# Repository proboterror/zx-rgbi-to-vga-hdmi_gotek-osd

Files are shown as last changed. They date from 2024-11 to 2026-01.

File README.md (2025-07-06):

# zx-rgbi-to-vga-hdmi

For detailed hardware and original software information, please refer to the source: [ZX_RGBI2VGA-HDMI](https://github.com/AlexEkb4ever/ZX_RGBI2VGA-HDMI/).

## Changes and New Features

### Software

- **Video Output:**
  - Added new resolutions on VGA output (800x600, 1024x768, 1280x1024).
  - Introduced scanline effect at higher resolutions.
- **Configuration via Serial Terminal:**
  - Text-based menus.
  - Frequency presets for self-synchronizing capture mode (supports ZX Spectrum 48K/128K timings).
  - Real-time settings adjustments for capture delay, image position, scanline effects, and buffering modes.
- **PIO Clock Divider Optimization:** Enhanced precision in self-synchronizing capture mode.
- **Test/Welcome Screen:** Styled like the ZX Spectrum 128K.
- **GOTEK floppy drive emulator [I2C OSD](ZX_RGBI_TO_VGA_HDMI/gotek_i2c_osd.c):** [FlashFloppy](https://github.com/keirf/flashfloppy) firmware I2C 40x4 on-screen display, VGA and HDMI output supported.
- **PS/2 Keyboard:** PS/2 - ZX Spectrum 58-key extended keyboard interface with CH446Q analog switch array in serial mode.
- **GOTEK control:** Navigate FlashFloppy menu with PS/2 keyboard.

### Hardware

- **Analog to Digital Conversion:** Converts Analog RGB to digital RGBI.
  - Based on the [RGBtoHDMI](https://github.com/hoglet67/RGBtoHDMI) project.

### Removed Features

- Z80 CLK external clock source.

# GOTEK floppy drive emulator with flashfloppy firmware I2C LCD OSD interface.

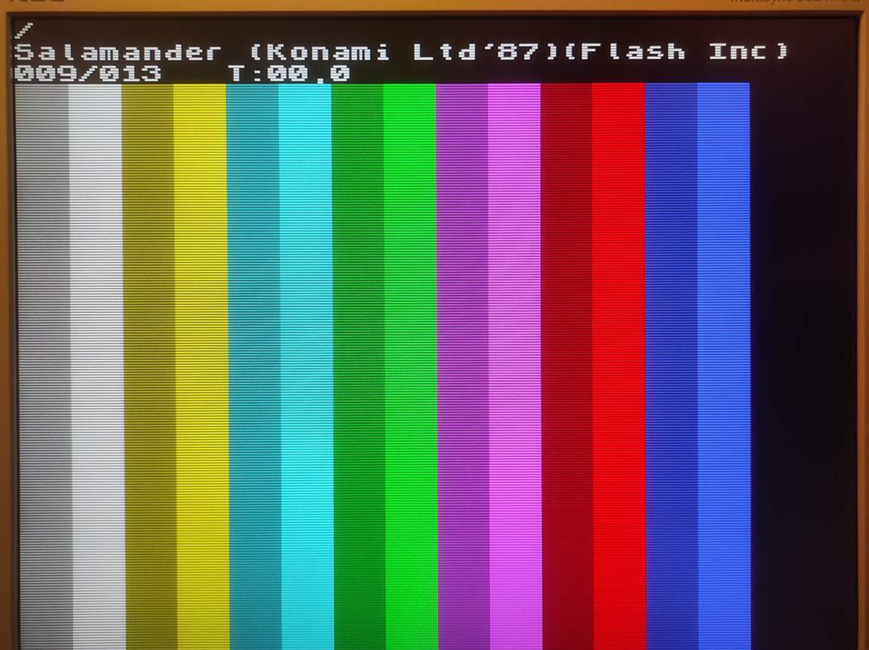
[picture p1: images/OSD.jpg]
OSD


_TL;DR: Connect GOTEK SDA and SCL pins to Pico GP16/GP17 pins (GP26/27 for RP2040-Zero). SDA and SCL lines should be pulled up to 3.3V with 4.7~10K resistors. Also support PS/2 keyboard for ZX Spectrum and OSD control._

VGA and HDMI OSD output implemented.<br>
OSD can be controlled with connected PS/2 keyboard.

Based on [flashfloppy-osd](https://github.com/keirf/flashfloppy-osd/) 1.9 by Keir Fraser<br>
Implementation: [github.com/proboterror](https://github.com/proboterror)

I2C communications to the host:
1. Emulate HD44780 LCD controller via a PCF8574 I2C backpack. Supported screen size 20x4 characters.
2. Support extended custom FF OSD protocol with bidirectional comms, up to 40x4 characters.

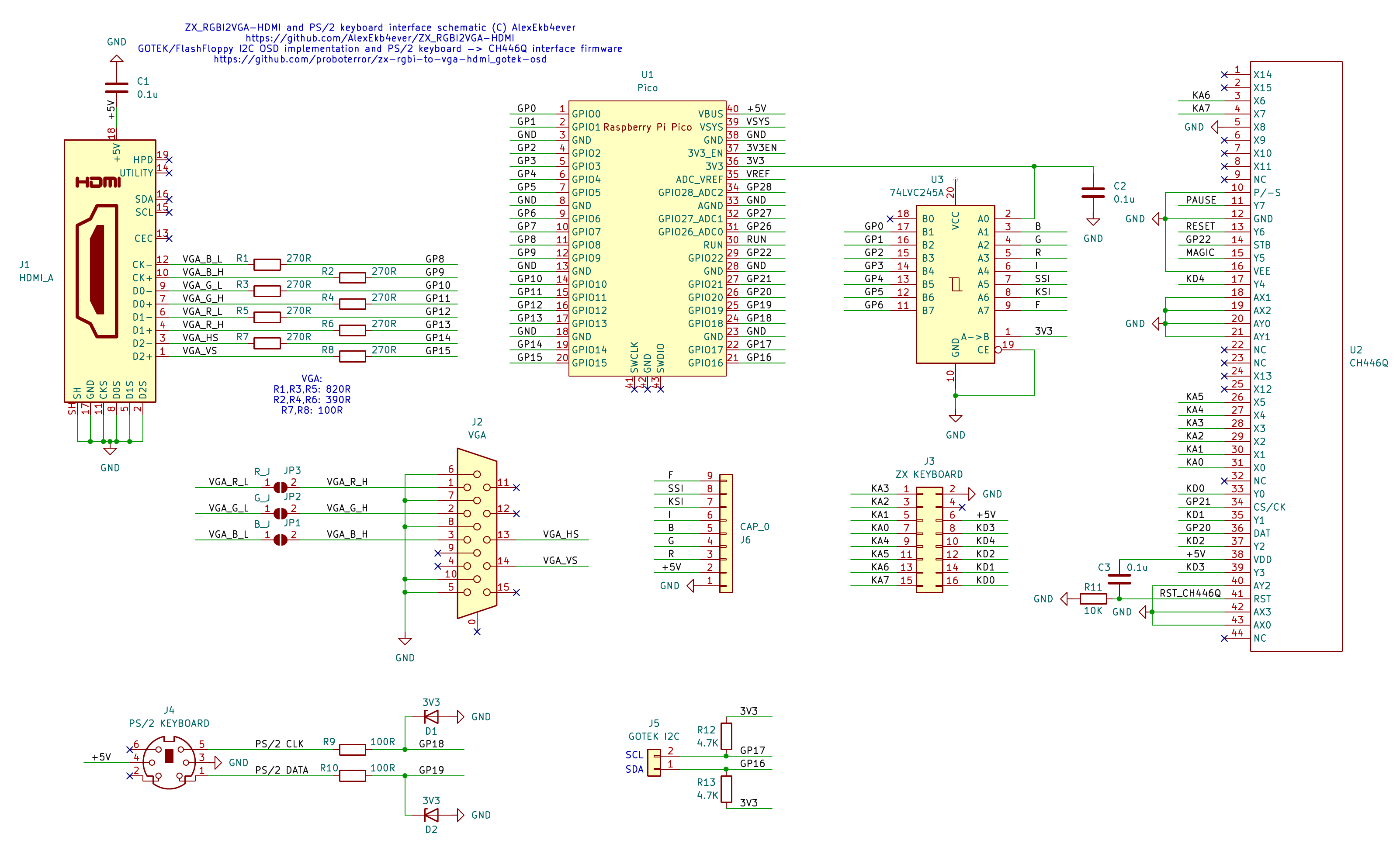
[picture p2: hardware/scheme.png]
scheme


## Compile:

Use Visual Studio Code.

Install "Arduino Community Edition" extension.<br>
Check and correct paths to rp2040 packages / Arduino CLI executable in .vscode/c_cpp_properties.json and scripts/make.ps1.

Run "Terminal/Run Task.../Build"

Do not use Arduino IDE, it uses different SDK / libraries resulting in capture sync issues.

Add
'#define WAVESHARE_RP2040_ZERO'
in g_config.h when targeting WaveShare RP2040-Zero.

## RP Pico Configuration:
- Connect host computer to Raspberry Pi Pico USB. Do not forget to disconnect +5V line from ZX.
- Use putty / minicom to connect to RP Pico COM port (9600 baud).<br>
- Press 'h' for menu help.

## GOTEK/FlashFloppy OSD wiring:
I2C OSD uses 2 wires: SDA and SCL to connect RGBI2VGA adapter and GOTEK. Connect GOTEK SDA and SCL pins to Pico GP16/GP17 pins. SDA and SCL lines should be pulled up to VCC(3.3V) with 4.7~10K resistors on GOTEK or RGBI2VGA side.

OSD also can be used with any device supporting LCD PCF8574 16x2/20x4 protocol.

WaveShare RP2040-Zero board supported with keyboard interface disabled (GP26/GP27 for SDA/SCL).

## GOTEK/FlashFloppy configuration:
GOTEK configuration:<br>
[flashfloppy/wiki/Hardware-Mods#lcd-display](https://github.com/keirf/flashfloppy/wiki/Hardware-Mods#lcd-display)<br>
[flashfloppy/wiki/FF.CFG-Configuration-File](https://github.com/keirf/flashfloppy/wiki/FF.CFG-Configuration-File)

FF.CFG:<br>
for FF OSD protocol with dual OLED/LCD support:<br>
set:
`display-type=auto`
or
`display-type = oled-128x64`
with
`osd-display-order = 3,0`
`osd-columns = 40`
and
`display-off-secs = 0-255 (60 by default)`

display-order and osd-display-order can be set independently.

for single PCF8574 20x4 LCD display protocol:<br>
set:
`display-type=lcd-20x04`
with
`display-order=3,0,2,1`
and
`display-off-secs = 0-255 (60 by default)`

Russian filenames are supported, requires [flashfloppy-russian](https://github.com/proboterror/flashfloppy-russian) patched flashfloppy GOTEK firmware.

## PS/2 Keyboard support:
- Selected USB keyboards can be used with passive USB->PS/2 adapter: requires explicit support in keyboard's internal controller. Not tested.

## GOTEK/FlashFloppy OSD hotkeys:
- CTRL+RIGHT - right
- CTRL+LEFT - left
- CTRL+UP - directory up
- CTRL+DOWN - select item

## Special keys:
- F10 - PAUSE (Z80 BUSRQ/) (trigger)
- F11 - MAGIC (Z80 NMI/)
- F12 - RESET (Z80 RST/)

## Special keys wiring:
- Input: CH446Q pin 5: common/GND
- Output: CH446Q pin 15: MAGIC, pin 13: RESET, pin 11: PAUSE.

## Test features:
Ветка с реализацией поддержки [SetupGUI](https://github.com/proboterror/zx-rgbi-to-vga-hdmi_gotek-osd/tree/SetupGUI) и доработками от Дмитрий Стародубцев (@cinsler78).

Selectable runtime HDMI palettes in [separate branch](https://github.com/proboterror/zx-rgbi-to-vga-hdmi_gotek-osd/tree/hdmi_rgb-palette) (setting save not implemented).

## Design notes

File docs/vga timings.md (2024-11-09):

# VGA timings

The table contains the timing parameters for all VGA modes supported in this project.

| Mode | 640 x 480 | | 800 x 600 | | 1024 x 768 | | 1280 x 1024 | |
|---|---:|---:|---:|---:|---:|---:|---:|---:|
| **Screen refresh rate** | 60 Hz | | 60 Hz | | 60 Hz | | 60 Hz | |
| **Vertical refresh** | 31.46875 kHz | | 37.878787878788 kHz | | 48.363095238095 kHz | | 63.981042654028 kHz | |
| **Pixel frequency** | 25.175 MHz | | 40.0 MHz | | 65.0 MHz | | 108.0 MHz | |
| | | | | | | | | |
| **Horizontal timing (line)** | | | | | | | | |
| **Polarity of horizontal sync pulse** | negative | | positive | | negative | | positive | |
| **Scanline part** | **Pixels** | **Time [µs]** | **Pixels** | **Time [µs]** | **Pixels** | **Time [µs]** | **Pixels** | **Time [µs]** |
| **Visible area** | 640 | 25.422045680238 | 800 | 20 | 1024 | 15.753846153846 | 1280 | 11.851851851852 |
| **Front porch** | 16 | 0.63555114200596  | 40 | 1 | 24 | 0.36923076923077  | 48 | 0.44444444444444  |
| **Sync pulse** | 96 | 3.8133068520357 | 128 | 3.2 | 136 | 2.0923076923077 | 112 | 1.037037037037 |
| **Back porch** | 48 | 1.9066534260179 | 88 | 2.2 | 160 | 2.4615384615385 | 248 | 2.2962962962963 |
| **Whole line** | 800 | 31.777557100298 | 1056 | 26.4 | 1344 | 20.676923076923 | 1688 | 15.62962962963 |
| | | | | | | | | |
| **Vertical timing (frame)** | | | | | | | | |
| **Polarity of vertical sync pulse** | negative | | positive | | negative | | positive | |
| **Frame part** | **Lines** | **Time [µs]** | **Lines** | **Time [µs]** | **Lines** | **Time [µs]** | **Lines** | **Time [µs]** |
| **Visible area** | 480 | 15.253227408143 | 600 | 15.84 | 768 | 15.879876923077 | 1024 | 16.004740740741 |
| **Front porch** | 10 | 0.31777557100298  | 1 | 0.0264 | 3 | 0.062030769230769 | 1 | 0.01562962962963  |
| **Sync pulse** | 2 | 0.063555114200596 | 4 | 0.1056 | 6 | 0.12406153846154  | 3 | 0.046888888888889 |
| **Back porch** | 33 | 1.0486593843098 | 23 | 0.6072 | 29 | 0.59963076923077  | 38 | 0.59392592592593  |
| **Whole frame** | 525 | 16.683217477656 | 628 | 16.5792 | 806 | 16.6656 | 1066 | 16.661185185185 |

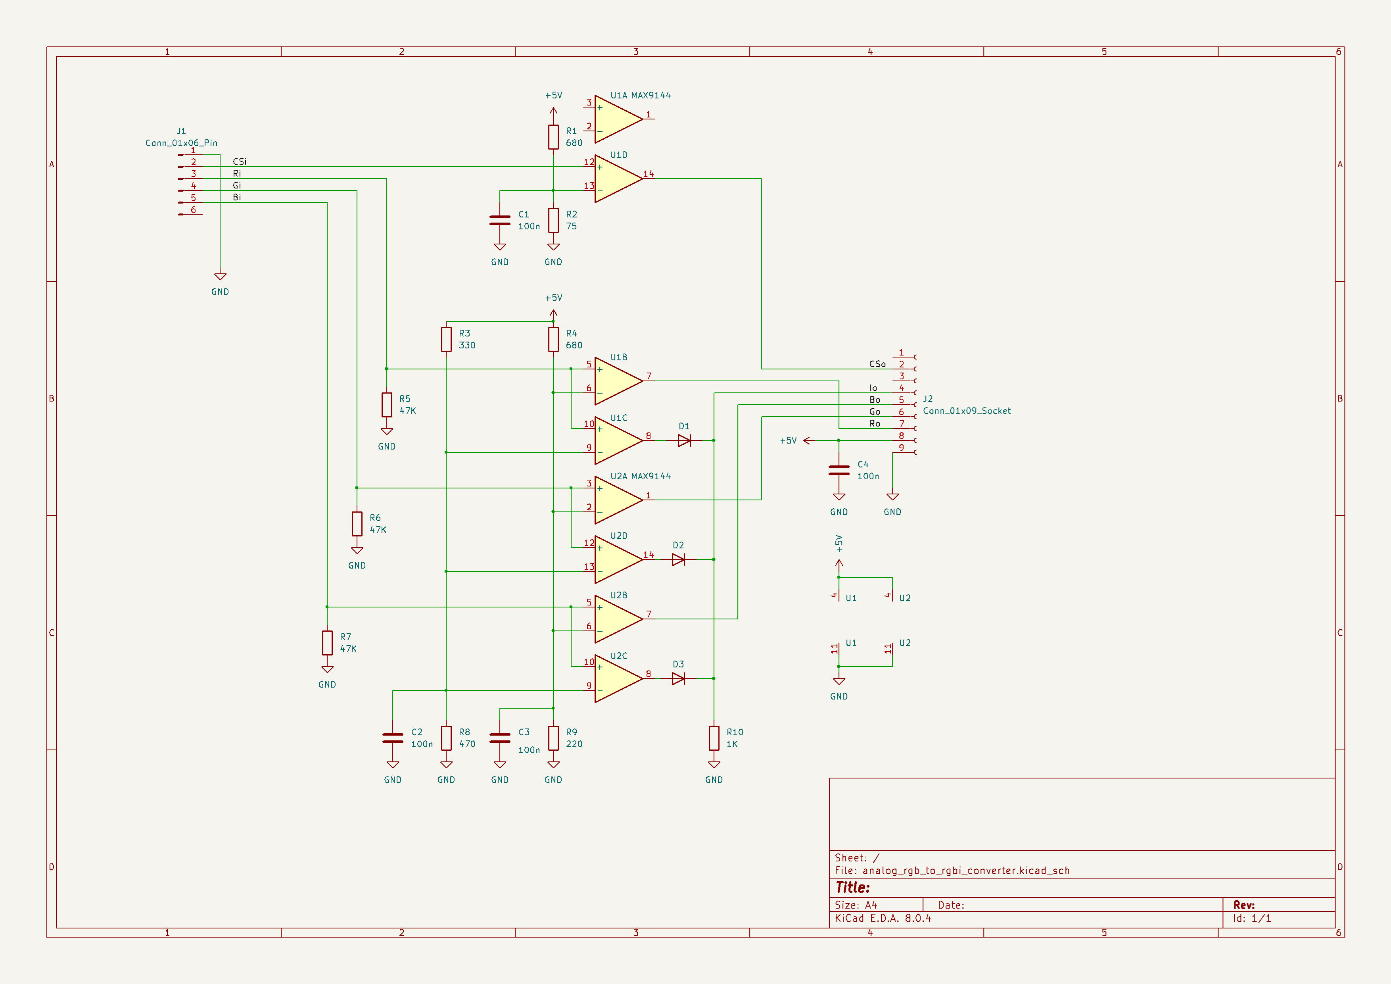
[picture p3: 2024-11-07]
hardware/analog_rgb_to_rgbi_converter.png

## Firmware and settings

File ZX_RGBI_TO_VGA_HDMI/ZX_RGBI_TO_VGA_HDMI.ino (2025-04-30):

#include <Arduino.h>
#include <typeinfo>

extern "C"
{
#include "g_config.h"
#include "dvi.h"
#include "rgb_capture.h"
#include "v_buf.h"
#include "vga.h"
#include "gotek_i2c_osd.h"
#include "ps2_keyboard.h"
#include "zx_keyboard.h"

#include "hardware/flash.h"
}

// Default settings values for Deltagon 1.6+
settings_t settings = {
  .video_out_mode = DVI,
  .scanlines_mode = false,
  .x3_buffering_mode = false,
  .video_sync_mode = true,
  .cap_sync_mode = EXT,
  .frequency = 7000000,
  .ext_clk_divider = 1,
  .delay = 20,
  .shX = 137,
  .shY = 40,
  .pin_inversion_mask = 0b01011111,
};

video_mode_t video_mode;

const int *saved_settings = (const int *)(XIP_BASE + (PICO_FLASH_SIZE_BYTES - FLASH_SECTOR_SIZE));
bool start_core0 = false;

// https://en.wikipedia.org/wiki/Fletcher's_checksum
uint16_t Fletcher16(uint8_t *data, int count)
{
  uint16_t sum1 = 0;
  uint16_t sum2 = 0;
  int index;

  for (index = 0; index < count; ++index)
  {
    sum1 = (sum1 + data[index]) % 255;
    sum2 = (sum2 + sum1) % 255;
  }

  return (sum2 << 8) | sum1;
}

struct flash_settings_t
{
  settings_t settings;
  uint16_t checksum;
};

void save_settings(settings_t *settings)
{
  Serial.println("  Saving settings...");

  check_settings(settings);

  flash_settings_t* flash_settings = (flash_settings_t*)malloc(FLASH_PAGE_SIZE);

  *flash_settings = {
    *settings,
    Fletcher16((uint8_t*)settings, sizeof(settings_t))
  };

  rp2040.idleOtherCore();
  uint32_t ints = save_and_disable_interrupts();

  flash_range_erase((PICO_FLASH_SIZE_BYTES - FLASH_SECTOR_SIZE), FLASH_SECTOR_SIZE);
  flash_range_program((PICO_FLASH_SIZE_BYTES - FLASH_SECTOR_SIZE), (uint8_t *)flash_settings, FLASH_PAGE_SIZE);

  // restore_interrupts(ints);
  // rp2040.resumeOtherCore();
}

void print_byte_hex(uint8_t byte)
{
  if (byte < 16)
    Serial.print("0");

  Serial.print(byte, HEX);
}

String binary_to_string(uint8_t value, bool mask_1)
{
  uint8_t binary = value;
  String str = "";

  for (int i = 0; i < 8; i++)
  {
    str += binary & 0b10000000 ? (mask_1 ? "X" : "1") : "0";
    binary <<= 1;
  }

  return str;
}

void print_main_menu()
{
  Serial.println("");
  Serial.print("      * ZX RGB(I) to VGA/HDMI ");
  Serial.print(FW_VERSION);
  Serial.println(" *");
  Serial.println("");
  Serial.println("  v   set video output mode");
  Serial.println("  s   set scanlines mode");
  Serial.println("  b   set buffering mode");
  Serial.println("  c   set capture synchronization source");
  Serial.println("  f   set capture frequency");
  Serial.println("  d   set external clock divider");
  Serial.println("  y   set video sync mode");
  Serial.println("  t   set capture delay and image position");
  Serial.println("  m   set pin inversion mask");
  Serial.println("");
  Serial.println("  p   show configuration");
  Serial.println("  h   show help (this menu)");
  Serial.println("  q   exit configuration mode");
  Serial.println("  w   save configuration and restart");
  Serial.println("");
}

void print_video_out_menu()
{
  Serial.println("");
  Serial.println("      * Video output mode *");
  Serial.println("");
  Serial.println("  1   HDMI   640x480 (div 2)");
  Serial.println("  2   VGA    640x480 (div 2)");
  Serial.println("  3   VGA    800x600 (div 2)");
  Serial.println("  4   VGA   1024x768 (div 3)");
  Serial.println("  5   VGA  1280x1024 (div 3)");
  Serial.println("  6   VGA  1280x1024 (div 4)");
  Serial.println("");
  Serial.println("  p   show configuration");
  Serial.println("  h   show help (this menu)");
  Serial.println("  q   exit to main menu");
  Serial.println("");
}

void print_scanlines_mode_menu()
{
  Serial.println("");
  Serial.println("      * Scanlines mode *");
  Serial.println("");
  Serial.println("  s   change scanlines mode");
  Serial.println("");
  Serial.println("  p   show configuration");
  Serial.println("  h   show help (this menu)");
  Serial.println("  q   exit to main menu");
  Serial.println("");
}

void print_buffering_mode_menu()
{
  Serial.println("");
  Serial.println("      * Buffering mode *");
  Serial.println("");
  Serial.println("  b   change buffering mode");
  Serial.println("");
  Serial.println("  p   show configuration");
  Serial.println("  h   show help (this menu)");
  Serial.println("  q   exit to main menu");
  Serial.println("");
}

void print_cap_sync_mode_menu()
{
  Serial.println("");
  Serial.println("      * Capture synchronization source *");
  Serial.println("");
  Serial.println("  1   self-synchronizing");
  Serial.println("  2   external clock");
  Serial.println("");
  Serial.println("  p   show configuration");
  Serial.println("  h   show help (this menu)");
  Serial.println("  q   exit to main menu");
  Serial.println("");
}

void print_capture_frequency_menu()
{
  Serial.println("");
  Serial.println("      * Capture frequency *");
  Serial.println("");
  Serial.println("  1   7000000 Hz (ZX Spectrum  48K)");
  Serial.println("  2   7093790 Hz (ZX Spectrum 128K)");
  Serial.println("  3   custom");
  Serial.println("");
  Serial.println("  p   show configuration");
  Serial.println("  h   show help (this menu)");
  Serial.println("  q   exit to main menu");
  Serial.println("");
}

void print_ext_clk_divider_menu()
{
  Serial.println("");
  Serial.println("      * External clock divider *");
  Serial.println("");
  Serial.println("  a   increment divider (+1)");
  Serial.println("  z   decrement divider (-1)");
  Serial.println("");
  Serial.println("  p   show configuration");
  Serial.println("  h   show help (this menu)");
  Serial.println("  q   exit to main menu");
  Serial.println("");
}

void print_video_sync_mode_menu()
{
  Serial.println("");
  Serial.println("      * Video synchronization mode *");
  Serial.println("");
  Serial.println("  y   change synchronization mode");
  Serial.println("");
  Serial.println("  p   show configuration");
  Serial.println("  h   show help (this menu)");
  Serial.println("  q   exit to main menu");
  Serial.println("");
}

void print_image_tuning_menu()
{
  Serial.println("");
  Serial.println("      * Capture delay and image position *");
  Serial.println("");
  Serial.println("  a   increment delay (+1)");
  Serial.println("  z   decrement delay (-1)");
  Serial.println("");
  Serial.println("  i   shift image UP");
  Serial.println("  k   shift image DOWN");
  Serial.println("  j   shift image LEFT");
  Serial.println("  l   shift image RIGHT");
  Serial.println("");
  Serial.println("  p   show configuration");
  Serial.println("  h   show help (this menu)");
  Serial.println("  q   exit to main menu");
  Serial.println("");
}

void print_pin_inversion_mask_menu()
{
  Serial.println("");
  Serial.println("      * Pin inversion mask *");
  Serial.println("");
  Serial.println("  m   set pin inversion mask");
  Serial.println("");
  Serial.println("  p   show configuration");
  Serial.println("  h   show help (this menu)");
  Serial.println("  q   exit to main menu");
  Serial.println("");
}

void print_test_menu()
{
  Serial.println("");
  Serial.println("      * Test *");
  Serial.println("");
  Serial.println("  1   draw welcome image (vertical stripes)");
  Serial.println("  2   draw welcome image (horizontal stripes)");
  Serial.println("  i   show captured frame count");
  Serial.println("");
  Serial.println("  p   show configuration");
  Serial.println("  h   show help (this menu)");
  Serial.println("  q   exit to main menu");
  Serial.println("");
}

void print_video_out_mode()
{
  Serial.print("  Video output mode ........... ");
  switch (settings.video_out_mode)
  {
  case DVI:
    Serial.println("HDMI 640x480");
    break;

  case VGA640x480:
    Serial.println("VGA 640x480");
    break;

  case VGA800x600:
    Serial.println("VGA 800x600");
    break;

  case VGA1024x768:
    Serial.println("VGA 1024x768");
    break;

  case VGA1280x1024_d3:
    Serial.println("VGA 1280x1024 (div 3)");
    break;

  case VGA1280x1024_d4:
    Serial.println("VGA 1280x1024 (div 4)");
    break;

  default:
    break;
  }
}

void print_scanlines_mode()
{
  Serial.print("  Scanlines ................... ");

  if (settings.scanlines_mode)
    Serial.println("enabled");
  else
    Serial.println("disabled");
}

void print_buffering_mode()
{
  Serial.print("  Buffering mode .............. ");

  if (settings.x3_buffering_mode)
    Serial.println("x3");
  else
    Serial.println("x1");
}

void print_cap_sync_mode()
{
  Serial.print("  Capture sync source ......... ");
  switch (settings.cap_sync_mode)
  {
  case SELF:
    Serial.println("self-synchronizing");
    break;

  case EXT:
    Serial.println("external clock");
    break;

  default:
    break;
  }
}

void print_capture_frequency()
{
  Serial.print("  Capture frequency ........... ");
  Serial.print(settings.frequency, DEC);
  Serial.println(" Hz");
}

void print_ext_clk_divider()
{
  Serial.print("  External clock divider ...... ");
  Serial.println(settings.ext_clk_divider, DEC);
}

void print_capture_delay()
{
  Serial.print("  Capture delay ............... ");
  Serial.println(settings.delay, DEC);
}

void print_x_offset()
{
  Serial.print("  X offset .................... ");
  Serial.println(settings.shX, DEC);
}

void print_y_offset()
{
  Serial.print("  Y offset .................... ");
  Serial.println(settings.shY, DEC);
}

void print_dividers()
{
  uint16_t div_int;
  uint8_t div_frac;

  video_mode_t video_mode = *(vga_modes[settings.video_out_mode]);

  Serial.println("");

  Serial.print("  System clock frequency ...... ");
  Serial.print(clock_get_hz(clk_sys), 1);
  Serial.println(" Hz");

  Serial.println("  Capture divider");

  Serial.print("    calculated (SDK) .......... ");

  pio_calculate_clkdiv_from_float((float)clock_get_hz(clk_sys) / (settings.frequency * 12.0), &div_int, &div_frac);

  Serial.print((div_int + (float)div_frac / 256), 8);

  Serial.print(" ( ");
  Serial.print("0x");
  print_byte_hex((uint8_t)(div_int >> 8));
  print_byte_hex((uint8_t)(div_int & 0xff));
  print_byte_hex(div_frac);
  Serial.println(" )");

  Serial.print("    optimized ................. ");

  calculate_clkdiv(settings.frequency, &div_int, &div_frac);

  Serial.print((div_int + (float)div_frac / 256), 8);

  Serial.print(" ( ");
  Serial.print("0x");
  print_byte_hex((uint8_t)(div_int >> 8));
  print_byte_hex((uint8_t)(div_int & 0xff));
  print_byte_hex(div_frac);
  Serial.println(" )");

  Serial.print("  Video output clock divider .. ");

  pio_calculate_clkdiv_from_float(((float)clock_get_hz(clk_sys) * video_mode.div) / video_mode.pixel_freq, &div_int, &div_frac);

  Serial.print((div_int + (float)div_frac / 256), 8);

  Serial.print(" ( ");
  Serial.print("0x");
  print_byte_hex((uint8_t)(div_int >> 8));
  print_byte_hex((uint8_t)(div_int & 0xff));
  print_byte_hex(div_frac);
  Serial.println(" )");

  Serial.println("");
}

void print_video_sync_mode()
{
  Serial.print("  Video synchronization mode .. ");
  if (settings.video_sync_mode)
    Serial.println("separate");
  else
    Serial.println("composite");
}

void print_pin_inversion_mask()
{
  Serial.print("  Pin inversion mask .......... ");
  Serial.println(binary_to_string(settings.pin_inversion_mask, false));
}

void print_settings()
{
  Serial.println("");
  print_video_out_mode();
  print_scanlines_mode();
  print_buffering_mode();
  print_cap_sync_mode();
  print_capture_frequency();
  print_ext_clk_divider();
  print_video_sync_mode();
  print_capture_delay();
  print_x_offset();
  print_y_offset();
  print_pin_inversion_mask();
  print_dividers();
  Serial.println("");
}

void set_scanlines_mode()
{
  if (settings.video_out_mode != DVI)
    set_vga_scanlines_mode(settings.scanlines_mode);
}

void setup()
{
  setup_i2c_slave();
#ifndef WAVESHARE_RP2040_ZERO
  zx_keyboard_init();
  ps2_keyboard_init();
#endif
  Serial.begin(9600);

  // loading saved settings
  const flash_settings_t *flash_settings = (flash_settings_t*)saved_settings;
  const uint16_t checksum = Fletcher16((uint8_t*)saved_settings, sizeof(settings_t));

  if(checksum == flash_settings->checksum)
    memcpy(&settings, saved_settings, sizeof(settings_t));

  // correct if there is garbage in the cells
  check_settings(&settings);

  set_v_buf_buffering_mode(settings.x3_buffering_mode);

  draw_welcome_screen(*(vga_modes[settings.video_out_mode]));

  set_scanlines_mode();

  if (settings.video_out_mode == DVI)
  {
    start_dvi(*(vga_modes[settings.video_out_mode]));
  }
  else
  {
    start_vga(*(vga_modes[settings.video_out_mode]));
  }

  start_core0 = true;

  Serial.println("  Starting...");
  Serial.println("");
}

void loop()
{
  char inbyte = 0;

  while (1)
  {
    sleep_ms(500);

    if (Serial.available())
    {
      inbyte = 'h';
      break;
    }
  }

  Serial.println(" Entering the configuration mode");
  Serial.println("");

  while (1)
  {
    sleep_ms(10);

    if (inbyte != 'h' && Serial.available())
      inbyte = Serial.read();

    switch (inbyte)
    {
    case 'p':
      print_settings();
      inbyte = 0;
      break;

    case 'v':
    {
      inbyte = 'h';

      while (1)
      {
        sleep_ms(10);

        if (inbyte != 'h' && Serial.available())
          inbyte = Serial.read();

        switch (inbyte)
        {
        case 'p':
          print_video_out_mode();
          break;

        case 'h':
          print_video_out_menu();
          break;

        case '1':
          settings.video_out_mode = DVI;
          print_video_out_mode();
          break;

        case '2':
          settings.video_out_mode = VGA640x480;
          print_video_out_mode();
          break;

        case '3':
          settings.video_out_mode = VGA800x600;
          print_video_out_mode();
          break;

        case '4':
          settings.video_out_mode = VGA1024x768;
          print_video_out_mode();
          break;

        case '5':
          settings.video_out_mode = VGA1280x1024_d3;
          print_video_out_mode();
          break;
        case '6':
          settings.video_out_mode = VGA1280x1024_d4;
          print_video_out_mode();
          break;

        default:
          break;
        }

        if (inbyte == 'q')
        {
          inbyte = 'h';
          break;
        }

        inbyte = 0;
      }

      break;
    }

    case 's':
    {
      inbyte = 'h';

      while (1)
      {
        sleep_ms(10);

        if (inbyte != 'h' && Serial.available())
          inbyte = Serial.read();

        switch (inbyte)
        {
        case 'p':
          print_scanlines_mode();
          break;

        case 'h':
          print_scanlines_mode_menu();
          break;

        case 's':
          settings.scanlines_mode = !settings.scanlines_mode;
          print_scanlines_mode();
          set_scanlines_mode();
          break;

        default:
          break;
        }

        if (inbyte == 'q')
        {
          inbyte = 'h';
          break;
        }

        inbyte = 0;
      }

      break;
    }

    case 'b':
    {
      inbyte = 'h';

      while (1)
      {
        sleep_ms(10);

        if (inbyte != 'h' && Serial.available())
          inbyte = Serial.read();

        switch (inbyte)
        {
        case 'p':
          print_buffering_mode();
          break;

        case 'h':
          print_buffering_mode_menu();
          break;

        case 'b':
          settings.x3_buffering_mode = !settings.x3_buffering_mode;
          print_buffering_mode();
          set_v_buf_buffering_mode(settings.x3_buffering_mode);
          break;

        default:
          break;
        }

        if (inbyte == 'q')
        {
          inbyte = 'h';
          break;
        }

        inbyte = 0;
      }

      break;
    }

    case 'c':
    {
      inbyte = 'h';

      while (1)
      {
        sleep_ms(10);

        if (inbyte != 'h' && Serial.available())
          inbyte = Serial.read();

        switch (inbyte)
        {
        case 'p':
          print_cap_sync_mode();
          break;

        case 'h':
          print_cap_sync_mode_menu();
          break;

        case '1':
          settings.cap_sync_mode = SELF;
          print_cap_sync_mode();
          break;

        case '2':
          settings.cap_sync_mode = EXT;
          print_cap_sync_mode();
          break;

        default:
          break;
        }

        if (inbyte == 'q')
        {
          inbyte = 'h';
          break;
        }

        inbyte = 0;
      }

      break;
    }

    case 'f':
    {
      inbyte = 'h';

      while (1)
      {
        sleep_ms(10);

        if (inbyte != 'h' && Serial.available())
          inbyte = Serial.read();

        switch (inbyte)
        {
        case 'p':
          print_capture_frequency();
          break;

        case 'h':
          print_capture_frequency_menu();
          break;

        case '1':
          settings.frequency = 7000000;
          print_capture_frequency();
          break;

        case '2':
          settings.frequency = 7093790;
          print_capture_frequency();
          break;

        case '3':
        {
          String str_frequency = "";
          uint32_t frequency = 0;

          Serial.print("  Enter frequency: ");

          while (1)
          {
            sleep_ms(10);
            inbyte = 0;

            if (Serial.available())
              inbyte = Serial.read();

            if (inbyte >= '0' && inbyte <= '9')
            {
              Serial.print(inbyte);
              str_frequency += inbyte;
            }

            if (inbyte == '\r')
            {
              Serial.println("");
              frequency = str_frequency.toInt();

              if (frequency >= FREQUENCY_MIN && frequency <= FREQUENCY_MAX)
              {
                settings.frequency = frequency;
                print_capture_frequency();
                break;
              }
              else
              {
                str_frequency = "";
                Serial.print("  Allowed frequency range ..... ");
                Serial.print(FREQUENCY_MIN, DEC);
                Serial.print(" - ");
                Serial.print(FREQUENCY_MAX, DEC);
                Serial.println(" Hz");
                Serial.print("  Enter frequency: ");
              }
            }
          }

          break;
        }

        default:
          break;
        }

        if (inbyte == 'q')
        {
          inbyte = 'h';
          break;
        }

        inbyte = 0;
      }

      break;
    }

    case 'd':
    {
      inbyte = 'h';

      while (1)
      {
        sleep_ms(10);

        if (inbyte != 'h' && Serial.available())
          inbyte = Serial.read();

        switch (inbyte)
        {

        case 'p':
          print_ext_clk_divider();
          break;

        case 'h':
          print_ext_clk_divider_menu();
          break;

        case 'a':
          settings.ext_clk_divider = settings.ext_clk_divider < EXT_CLK_DIVIDER_MAX ? (settings.ext_clk_divider + 1) : EXT_CLK_DIVIDER_MAX;
          print_ext_clk_divider();
          break;

        case 'z':
          settings.ext_clk_divider = settings.ext_clk_divider > EXT_CLK_DIVIDER_MIN ? (settings.ext_clk_divider - 1) : EXT_CLK_DIVIDER_MIN;
          print_ext_clk_divider();
          break;

        default:
          break;
        }

        if (inbyte == 'q')
        {
          inbyte = 'h';
          break;
        }

        inbyte = 0;
      }

      break;
    }

    case 'y':
    {
      inbyte = 'h';

      while (1)
      {
        sleep_ms(10);

        if (inbyte != 'h' && Serial.available())
          inbyte = Serial.read();

        switch (inbyte)
        {
        case 'p':
          print_video_sync_mode();
          break;

        case 'h':
          print_video_sync_mode_menu();
          break;

        case 'y':
          settings.video_sync_mode = !settings.video_sync_mode;
          print_video_sync_mode();
          set_video_sync_mode(settings.video_sync_mode);
          break;

        default:
          break;
        }

        if (inbyte == 'q')
        {
          inbyte = 'h';
          break;
        }

        inbyte = 0;
      }

      break;
    }

    case 't':
    {
      inbyte = 'h';

      while (1)
      {
        sleep_ms(10);

        if (inbyte != 'h' && Serial.available())
          inbyte = Serial.read();

        switch (inbyte)
        {

        case 'p':
          print_capture_delay();
          print_x_offset();
          print_y_offset();
          break;

        case 'h':
          print_image_tuning_menu();
          break;

        case 'a':
          settings.delay = set_capture_delay(settings.delay + 1);
          print_capture_delay();
          break;

        case 'z':
          settings.delay = set_capture_delay(settings.delay - 1);
          print_capture_delay();
          break;

        case 'i':
          settings.shY = set_capture_shY(settings.shY + 1);
          print_y_offset();
          break;

        case 'k':
          settings.shY = set_capture_shY(settings.shY - 1);
          print_y_offset();
          break;

        case 'j':
          settings.shX = set_capture_shX(settings.shX - 1);
          print_x_offset();
          break;

        case 'l':
          settings.shX = set_capture_shX(settings.shX + 1);
          print_x_offset();
          break;

        default:
          break;
        }

        if (inbyte == 'q')
        {
          inbyte = 'h';
          break;
        }

        inbyte = 0;
      }

      break;
    }

    case 'm':
    {
      inbyte = 'h';

      while (1)
      {
        sleep_ms(10);

        if (inbyte != 'h' && Serial.available())
          inbyte = Serial.read();

        switch (inbyte)
        {
        case 'p':
          print_pin_inversion_mask();
          break;

        case 'h':
          print_pin_inversion_mask_menu();
          break;

        case 'm':
        {
          String str_pin_inversion_mask = "";
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

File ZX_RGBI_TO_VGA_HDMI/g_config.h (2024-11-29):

#ifndef G_CONFIG_H
#define G_CONFIG_H

#include <Arduino.h>

#include "pico/platform.h"
#include "pico/stdlib.h"

#include "stdio.h"
#include "inttypes.h"
#include "stdbool.h"

#define FW_VERSION "v1.2.1"

enum cap_sync_mode_t
{
  SYNC_MODE_MIN,
  SELF = SYNC_MODE_MIN,
  EXT,
  SYNC_MODE_MAX = EXT,
};

enum video_out_mode_t
{
  VIDEO_MODE_MIN,
  DVI = VIDEO_MODE_MIN,
  VGA640x480,
  VGA800x600,
  VGA1024x768,
  VGA1280x1024_d3,
  VGA1280x1024_d4,
  VIDEO_MODE_MAX = VGA1280x1024_d4,
};

typedef struct settings_t
{
  enum video_out_mode_t video_out_mode;
  bool scanlines_mode : 1;
  bool x3_buffering_mode : 1;
  bool video_sync_mode : 1;
  enum cap_sync_mode_t cap_sync_mode;
  uint32_t frequency;
  uint8_t ext_clk_divider;
  int8_t delay;
  int16_t shX;
  int16_t shY;
  uint8_t pin_inversion_mask;
} settings_t;

typedef struct video_mode_t
{
  uint32_t sys_freq;
  float pixel_freq;
  uint16_t h_visible_area;
  uint16_t v_visible_area;
  uint16_t whole_line;
  uint16_t whole_frame;
  uint8_t h_front_porch;
  uint8_t h_sync_pulse;
  uint8_t h_back_porch;
  uint8_t v_front_porch;
  uint8_t v_sync_pulse;
  uint8_t v_back_porch;
  uint8_t sync_polarity;
  uint8_t div;
} video_mode_t;

extern video_mode_t vga_640x480;
extern video_mode_t vga_800x600;
extern video_mode_t vga_1024x768;
extern video_mode_t vga_1280x1024_d3;
extern video_mode_t vga_1280x1024_d4;

extern video_mode_t *vga_modes[];

extern uint8_t g_v_buf[];
extern uint32_t frame_count;

#define BOARD_CODE_36LJU22
// #define BOARD_CODE_09LJV23

// board pin configurations
#ifdef BOARD_CODE_36LJU22
// 36LJU22
// first VGA pin
#define VGA_PIN_D0 8
// DVI pins and settings
#define DVI_PIN_D0 VGA_PIN_D0
#define DVI_PIN_CLK0 (DVI_PIN_D0 + 6)

#elif defined(BOARD_CODE_09LJV23)
// 09LJV23
// first VGA pin
#define VGA_PIN_D0 7
// DVI pins and settings
#define DVI_PIN_D0 VGA_PIN_D0
#define DVI_PIN_CLK0 (DVI_PIN_D0 + 6)

#else
// defaults
// first VGA pin
#define VGA_PIN_D0 7
// DVI pins and settings
#define DVI_PIN_D0 VGA_PIN_D0
#define DVI_PIN_CLK0 (DVI_PIN_D0 + 6)

#endif

// capture pins
#ifndef CAP_PIN_D0
#define CAP_PIN_D0 0
#endif

#ifndef HS_PIN
#define HS_PIN (CAP_PIN_D0 + 4)
#endif

#ifndef VS_PIN
#define VS_PIN (CAP_PIN_D0 + 5)
#endif

#ifndef F_PIN
#define F_PIN (CAP_PIN_D0 + 6)
#endif

// DVI pins and settings
#ifndef DVI_PIN_invert_diffpairs
#define DVI_PIN_invert_diffpairs 0
#endif

#ifndef DVI_PIN_RGB_notBGR
#define DVI_PIN_RGB_notBGR 0
#endif

// PIO and SM for VGA
#define PIO_VGA_NUM 0
#if PIO_VGA_NUM == 0
#define PIO_VGA pio0
#define DREQ_PIO_VGA DREQ_PIO0_TX0
#else
#define PIO_VGA pio1
#define DREQ_PIO_VGA DREQ_PIO1_TX0
#endif

#define SM_VGA 0

// PIO and SM for DVI
#define PIO_DVI_NUM 0
#if PIO_DVI_NUM == 0
#define PIO_DVI pio0
#define DREQ_PIO_DVI DREQ_PIO0_TX0
#else
#define PIO_DVI pio1
#define DREQ_PIO_DVI DREQ_PIO0_TX0
#endif

#define SM_DVI 0

// capture PIO and SM
#define PIO_CAP_NUM 1
#if PIO_CAP_NUM == 0
#define PIO_CAP pio0
#define DREQ_PIO_CAP DREQ_PIO0_RX0
#else
#define PIO_CAP pio1
#define DREQ_PIO_CAP DREQ_PIO1_RX0
#endif

#define SM_CAP 0

// video buffer
#define V_BUF_W 448
#define V_BUF_H 306
#define V_BUF_SZ (V_BUF_H * V_BUF_W / 2)

// settings MIN values
#define VIDEO_OUT_MODE_MIN VIDEO_MODE_MIN
#define CAP_SYNC_MODE_MIN SYNC_MODE_MIN
#define FREQUENCY_MIN 6000000
#define EXT_CLK_DIVIDER_MIN 1
#define DELAY_MIN 0
#define shX_MIN 0
#define shY_MIN 0

// settings MAX values
#define VIDEO_OUT_MODE_MAX VIDEO_MODE_MAX
#define CAP_SYNC_MODE_MAX SYNC_MODE_MAX
#define FREQUENCY_MAX 8000000
#define EXT_CLK_DIVIDER_MAX 5
#define DELAY_MAX 31
#define shX_MAX 200
#define shY_MAX 200
#define PIN_INVERSION_MASK 0x7f

#endif

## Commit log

2024-11-07 small code changes, spelling correction
    [ZX_RGBI_TO_VGA_HDMI.ino, g_config.h, hdmi.c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]
2024-11-09 fix: replaced HDMI with DVI in file names and code for correctness
    [ZX_RGBI_TO_VGA_HDMI.ino, dvi.c, g_config.h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]
2024-11-11 fix: separate video sync mode updated
    [rgb_capture.c]
2024-11-11 fix: improved 1280x1024 video output mode, fixed line jitter.
    [vga.c]
2024-11-14 fix: 1280x1024 div 3 is stable at 252MHz system clock
    [vga.c]
2024-11-15 fix: lowered system clock for 1280x1024 div4 mode, added FW version to help menu
    [ZX_RGBI_TO_VGA_HDMI.ino, g_config.h]
2024-11-29 fix: cleaned up stale code, updated toolset version, applied other minor changes
    [ZX_RGBI_TO_VGA_HDMI.ino, dvi.c, g_config.h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]
2024-12-26 Copy pico_i2c_slave library source from pico-sdk 4.3.1 (pico-sdk/src/rp2_common/pico_i2c_slave) ToDo: import pico_i2c_slave library CMake.
2024-12-26 Implement I2C 20x04 text LCD OSD interface for GOTEK flashfloppy firmware. VGA output implemented.
    Based on https://github.com/keirf/flashfloppy-osd/ by Keir Fraser
    Russian filenames are supported.
    8x13 font included.
    I2C SDA and SCL lines connected to Raspberry Pi Pico pins 16 and 17.
    SDA and SCL lines should be pulled up to VCC(3.3V) with 4.7K resistors.
2024-12-26 Add pin inversion mask input hint.
2024-12-28 Add link to I2C OSD source documentation to README.md.
2025-01-05 Implement FF OSD protocol.
    Up to 40x4 OSD display.
    Support simultaneous OSD and OLED display.
    OSD processing moved from I2C interrupt handler to loop1(), fixes VGA/HDMI display issues with FF OSD.
    #define FF_OSD_SUPPORT 1 enables FF OSD build.
    [ZX_RGBI_TO_VGA_HDMI.ino, gotek_i2c_osd.c]
2025-01-15 Speed up OSD line interrupt rendering with HDMI and VGA. Write to screen line data buffer once. Fixes sync issues with HDMI and more than 20 columns FF OSD.
    Apply __not_in_flash_func attribute to i2c_slave_handler, ff_osd_process, lcd_process, lcd_process_dat, lcd_process_cmd, render_i2c_osd_line (performance effect not profiled).
    Apply __not_in_flash attribute to OSD font pixel data (performance effect not profiled).
    [dvi.c, gotek_i2c_osd.c, vga.c]
2025-02-02 Implement interrupt-based PS/2 keyboard to ZX Spectrum 58-key keyboard matrix interface with CH446Q in serial mode.
2025-02-08 Fix OSD hotkeys handling with CTRL button.
2025-02-08 Add special PS/2 keyboard keys handling:
    F12: ZX_KEY_RESET: switch address: Y:6 X:8: push down-up
    F11: ZX_KEY_MAGIC: switch address: Y:5 X:8: push down-up
    F10: ZX_KEY_PAUSE: switch address: Y:7 X:8: toggle on push down
    CH446Q pins: X8:5, Y5:15, Y6:13, Y7:11.
    Skip ZX keys handling and special buttons F10, F11, F12 while CTRL modifier key pressed.
    Potential issue with ZX key pressed before CTRL pressed: ZX key release not processed.
2025-02-13 FlashFloppy OSD: emulate buttons Left + Right (move to parent directory) with CTRL+UP.
2025-03-10 Add Raspberry Pi Pico KiCad symbol and footprint from https://github.com/ncarandini/KiCad-RP-Pico
2025-03-10 Add original Nanjing Qinheng Microelectronics/WinChipHead/WCH CH446Q KiCad symbol.
2025-03-10 Add empty KiCad 8.0 project.
    [zx-rgbi-to-vga-hdmi_gotek-osd_keyboard.kicad_pcb, zx-rgbi-to-vga-hdmi_gotek-osd_keyboard.kicad_sch]
2025-03-10 Add KiCad schematic.
    [zx-rgbi-to-vga-hdmi_gotek-osd_keyboard.kicad_sch]
2025-03-26 Connect +5V to CH446Q VDD.
    [zx-rgbi-to-vga-hdmi_gotek-osd_keyboard.kicad_sch]
2025-03-26 Change CH446Q Y4 pin from power_in to output.
    [zx-rgbi-to-vga-hdmi_gotek-osd_keyboard.kicad_sch]
2025-03-28 CH446Q output Z80 control signals PAUSE, MAGIC, RESET have common input connected to GND.
    [zx-rgbi-to-vga-hdmi_gotek-osd_keyboard.kicad_sch]
2025-04-30 Add Waveshare RP2040-Zero board support with keyboard interface disabled. Use #define WAVESHARE_RP2040_ZERO in g_config.h for build target.
2025-04-30 Update README.md.
    Add WaveShare RP2040-Zero support.
    Remove Arduino IDE from build instructions.
2026-01-07 Change schematic for BOARD_CODE_36LJU22 (capture pins starts from GP0, HDMI/VGA data lines starts from GP8).
    [zx-rgbi-to-vga-hdmi_gotek-osd_keyboard.kicad_sch]
